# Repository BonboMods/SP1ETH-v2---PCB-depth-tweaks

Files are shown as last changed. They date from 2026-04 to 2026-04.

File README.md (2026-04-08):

# SP1ETH - PCB depth Tweaks(4-8-26)
DIY Adapter PCB and Case for SP1 on the Nintendo Gamecube for a ENC28J60 BBA based on the ETH2GC project by webhdx & Extrems

Must be used with the lastest version of Swiss as of 1788 in order to use the in game BBA features as it supports the hypervisor driver for games.

20250101_160555-min

**PCB**

Must be ordered from fab such as jlcpcb with 1.2mm thickness with ENIG surface finish

I used 10CM Female to Male dupont wires to connect the ENC28J60 Mini to the pcb but regular wires can be directly soldered to the pcb and ENC28J60 as well, make sure to follow the pinout below.

I also removed the little black retaining plastic on the ENC28J60 in order to push the dupont connectors closer to the pcb to allow more clearance when closing the case together but you can bend the pins some as I did in the images to help with the 2 case halves closing better.

If using the 10Pin IDC cable instead of dupont wires there's no need to remove the black retaining plastic on the module as the IDC connector is short enough to close the 2 case halves together.

The case is designed to just snap together without any hardware, printed on an FDM 3D printer in something stronger than PLA, I've used PLA+ as its less brittle.

**BOM**

| Item | Source |
| --- | --- |
| ENC28J60 Mini | https://www.aliexpress.us/item/2255800100119709.html |
| 10CM Dupont Female to Male Wires or 10Pin female IDC cable | Amazon/Aliexpress |
| 1.2MM PCB | JLCPCB/Fab House |
| Case Shell | 3D Printed |
| Optional 20x6x2mm Oval Rubber Foot | https://www.aliexpress.us/item/3256807864916472.html |

**Pinout**

| ENC28J60 | Connector PCB |
| --- | --- |
| GND | GND |
| VCC | 3v3 |
| CS | CS |
| SCK | CLK |
| SO | DI |
| SI | DO |
| INT | INT |

Pinout

pcb

ENC28J60IDC-min

20250125_231507-min

20250101_144940-min

20250101_145106-min

20250101_145139-min

20250101_145732-min

20250101_151721-min

20250101_160413-min

20250101_160510-min

20250101_160601-min

20250101_160623-min

20250101_160939(0)-min

rubberfoot-min

20250101_164624-min

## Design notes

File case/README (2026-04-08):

case file remixed from https://www.thingiverse.com/thing:6693459

The two parts are meant to be snapped together without any hardware, print using something stronger than PLA, I used PLA+ as it was less brittle and prone to snapping unlike regular PLA.

The insert case piece has grippers added to the model to improve fitment with the SP1 metal retaining springs on the gamecube for a more stable/better fit.

New versions above, V2 tweaks depth of PCB protrusion to have more contact with SP1 port on the Gamecube.

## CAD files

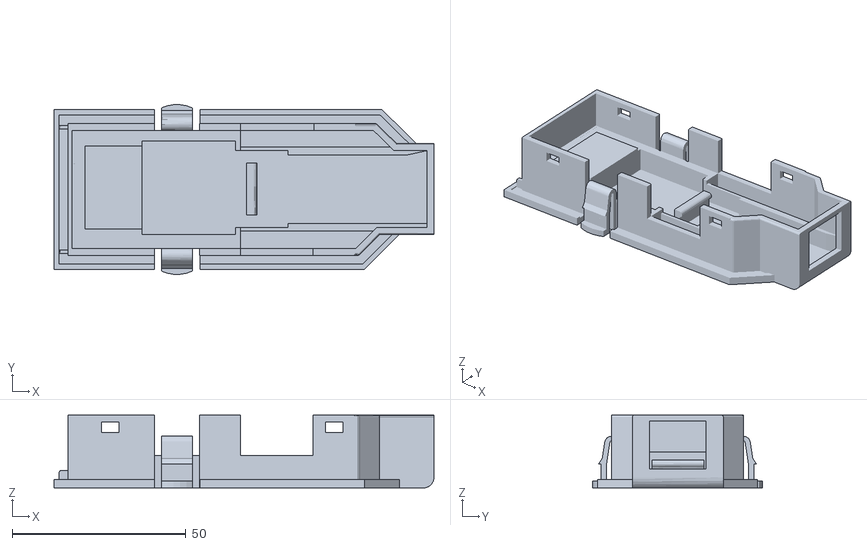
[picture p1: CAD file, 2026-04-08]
case/SP1ETH Part1 ENC18J60 v3.1V2.stl
109.5 x 48.9 x 21.0

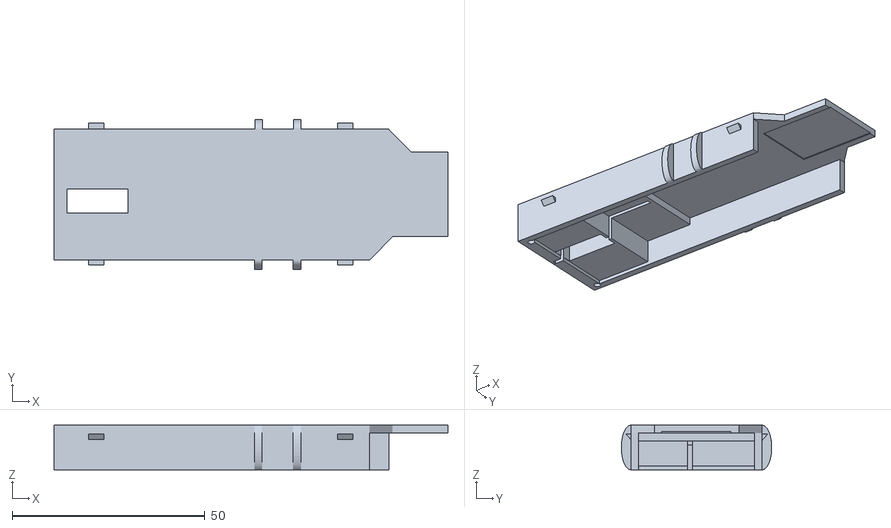
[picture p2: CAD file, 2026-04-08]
case/SP1ETH Part2 ENC18J60 v3.2GripV2.stl
102.1 x 39.0 x 11.6

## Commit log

2026-04-08 Delete case/pics directory
    Deleting to add diff pic
2026-04-08 Delete case/ENC18J60 InsertBottomv3.1.stl
    delete to add
    [ENC18J60 InsertBottomv3.1.stl]
2026-04-08 Delete case/ENC18J60 Insertv3.1.stl
    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
    [ENC18J60 Insertv3.1.stl]
2026-04-08 Delete case/ENC18J60 Insertv3.3Grip.stl
    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
    [ENC18J60 Insertv3.3Grip.stl]
2026-04-08 Update README with details on case version 3.3 v2
    Version 3.3 v2 adjusts PCB depth for better SP1 contact.
2026-04-08 Revise project title in README.md
    Updated project title to specify PCB depth tweaks.
2026-04-08 Fix typo in README regarding PCB protrusion
    Corrected spelling of 'protrusion' in the README.
2026-04-08 Clarify gripper addition for better fitment in README
    Updated README
